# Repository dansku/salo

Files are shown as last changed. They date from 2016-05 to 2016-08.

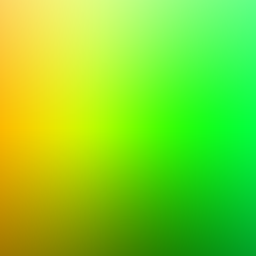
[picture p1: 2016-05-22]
vr/color_spectrum.framer/images/right.png

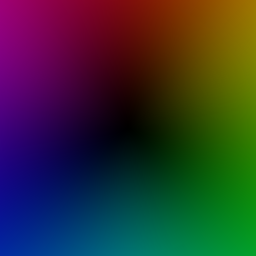
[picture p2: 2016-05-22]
vr/color_spectrum.framer/images/bottom.png

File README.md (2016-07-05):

# Salo Lamp

## Objectives 
* Develop a lamp connected to the internet where you can control it via a mobile application.
* Fully open source hardware/software
* Focus on low cost
* More to come...

## Dev Videos

<a href="http://www.youtube.com/watch?feature=player_embedded&v=c6tWdz0hgVQ
" target="_blank">salo lamp</a>

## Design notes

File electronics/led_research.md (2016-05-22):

# Led Research

http://aliexpress.com/store/product/10pcs-High-Power-LED-Chip-1W-COB-LED-Beads-Natural-Cool-Warm-White-Red-Blue-Green/1913069_32636756111.html

| Color | Temperature | [V] | [I] | [LM] |
|---|---|---|---|---|
| Red | 620-625nm | 2.0 - 2.2 V | 350mA | 50-60LM |
| Green | 520-525nm | 3.2 - 3.4 V | 350mA | 80-90LM |
| Blue | 460-470nm | 3.2 - 3.4 V | 350mA | 35-45LM |
| Warm White | 3000-3500 K | 3.2 - 3.4 V | 350mA | 100-110LM |

##Idea:

| Color | Number  | Total Current | Total Lumens |
|---|---|---|---|
| Warm White  | 4 | 1.4 A | 400 LM |
| Red | 6 | 2.1 A | 360 LM |
| Green | 4 | 1.4 A | 360 LM |
| Blue | 8 | 2.8 A | 360 LM |
| TOTAL (max) | 22 Leds | 7.7 A | 1480 LM |

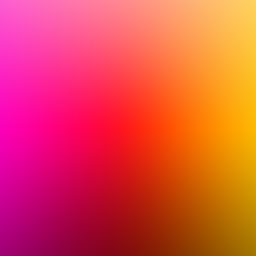
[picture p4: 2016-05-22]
vr/color_spectrum.framer/images/front.png

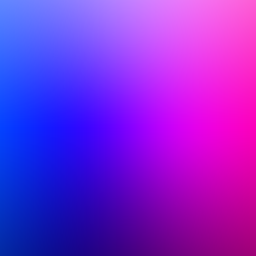
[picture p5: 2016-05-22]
vr/color_spectrum.framer/images/left.png

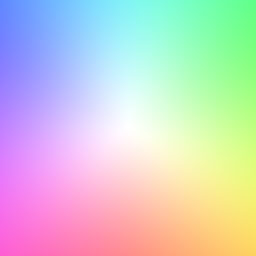
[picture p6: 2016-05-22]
vr/color_spectrum.framer/images/top.png

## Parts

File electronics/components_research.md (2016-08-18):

# Component Research

## Power Supply
https://www.reichelt.de/Wandler-Module-AC-DC/IRM-20-12/3/index.html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

## OSRAM LEDs
| Color | OSRAM Part Name | Temperature / Color | [V] | [I] | [LM] | Datasheet |
|---|---|---|---|---|---|---|
| Red | Q65111A2056 | 623 nm | 2.00 - 2.15 - 2.6  | 350mA | 58lm - 77lm/W  | http://bit.ly/2b00Kii |
| Green | Q65111A2266 | 528 nm | 2.75 - 3.20 - 3.5  | 350mA | 98 lm - 88lm/W | http://bit.ly/2b00ijR |
| Blue | Q65111A0403 | 470 nm | 2.75 - 3.20 - 3.5  | 350mA | 28 lm - 25lm/W | http://bit.ly/2aZZewz |
| Warm White | Q65111A3329 | 2700K | 2.80 - 2.95 - 3.25 | 350mA | 90 lm - 87lm/W | http://bit.ly/2b008ZZ |
| Cold White | Q65111A4248 | 4000K | 2.80 - 2.95 - 3.25 | 350mA | 90 lm - 87lm/W | http://bit.ly/2b008ZZ |

## LED Driver
AL5801W6-7 ( http://www.mouser.com/ds/2/115/AL5801-218664.pdf ) 350mA
VCC = 12V
Vrset = 0.56V
Iled = 350mA
Rbias = 82.5kOhm -> http://www.mouser.de/ProductDetail/Vishay-Dale/CRCW040282K5FKED/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
Rest = 1.6Ohm -> http://www.mouser.de/ProductDetail/Panasonic/ERJ-8GEYJ1R6V/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

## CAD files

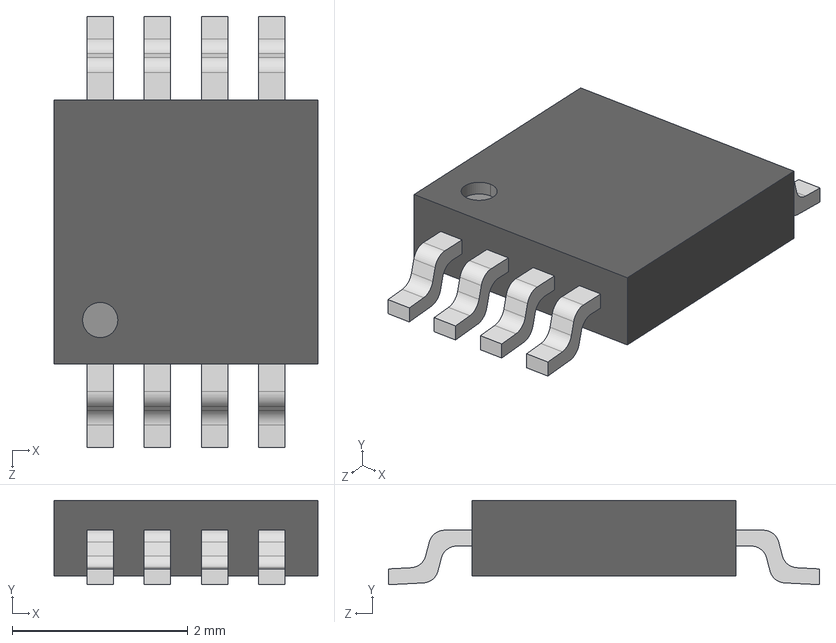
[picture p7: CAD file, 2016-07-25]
pcb/altium/components/User Library-MSOP-8-4.step
3.00 x 0.96 x 4.90 mm

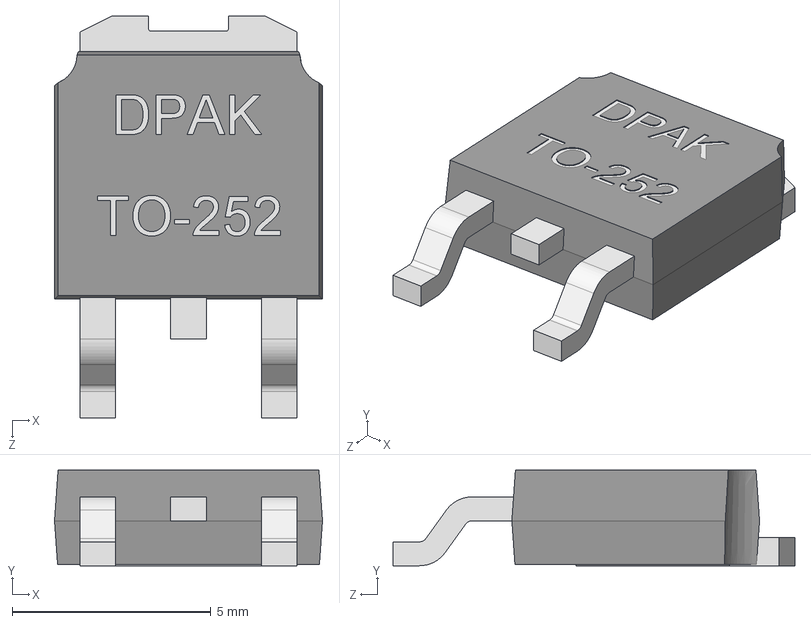
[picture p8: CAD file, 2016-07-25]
pcb/altium/components/DPAK_TO-252AA.step
6.73 x 2.40 x 10.1 mm

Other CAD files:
pcb/altium/components/DPAK_TO-252AA.stl

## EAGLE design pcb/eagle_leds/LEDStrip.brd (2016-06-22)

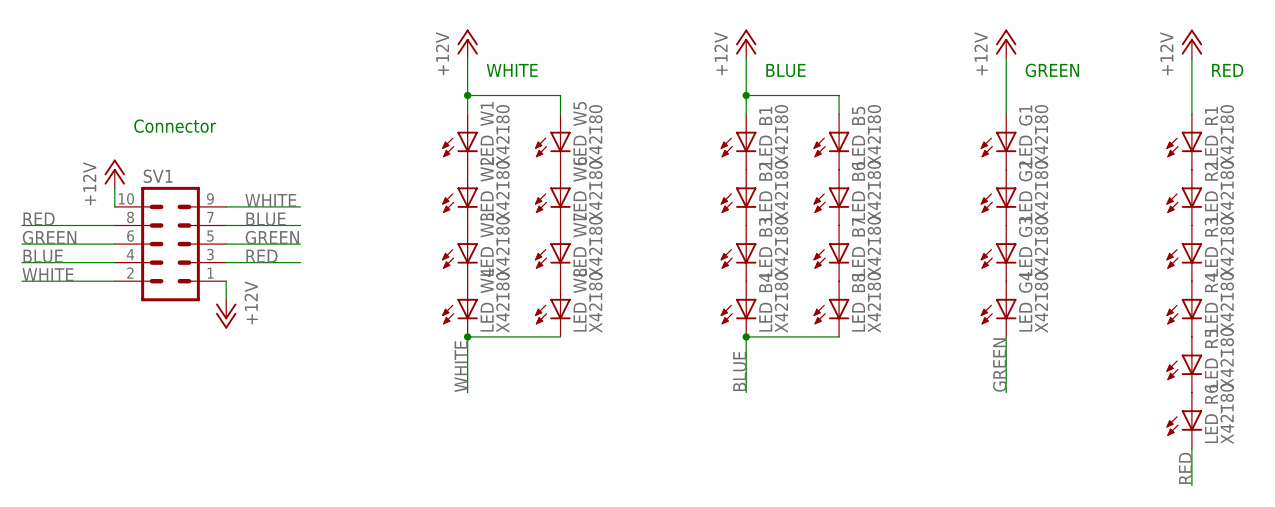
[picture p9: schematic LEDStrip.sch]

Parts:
LED_B1, LED_B2, LED_B3, LED_B4, LED_B5, LED_B6, LED_B7, LED_B8: X42180; Z-POWER-LED-DOME-TYPE
LED_G1, LED_G2, LED_G3, LED_G4: X42180; Z-POWER-LED-DOME-TYPE
LED_R1, LED_R2, LED_R3, LED_R4, LED_R5, LED_R6: X42180; Z-POWER-LED-DOME-TYPE
LED_W1, LED_W2, LED_W3, LED_W4, LED_W5, LED_W6, LED_W7, LED_W8: X42180; Z-POWER-LED-DOME-TYPE
SV1: MA05-2

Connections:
+12V: LED_B1.A, LED_B5.A, LED_G1.A, LED_R1.A, LED_W1.A, LED_W5.A, SV1.1, SV1.10
BLUE: LED_B4.C, LED_B8.C, SV1.4, SV1.7
GREEN: LED_G4.C, SV1.5, SV1.6
unnamed: LED_W1.C, LED_W2.A
unnamed: LED_W2.C, LED_W3.A
unnamed: LED_W3.C, LED_W4.A
unnamed: LED_W5.C, LED_W6.A
unnamed: LED_W6.C, LED_W7.A
unnamed: LED_W7.C, LED_W8.A
unnamed: LED_R4.C, LED_R5.A
unnamed: LED_B1.C, LED_B2.A
unnamed: LED_B2.C, LED_B3.A
unnamed: LED_B3.C, LED_B4.A
unnamed: LED_B5.C, LED_B6.A
unnamed: LED_B6.C, LED_B7.A
unnamed: LED_B7.C, LED_B8.A
unnamed: LED_G1.C, LED_G2.A
unnamed: LED_G2.C, LED_G3.A
unnamed: LED_G3.C, LED_G4.A
unnamed: LED_R1.C, LED_R2.A
unnamed: LED_R2.C, LED_R3.A
unnamed: LED_R3.C, LED_R4.A
unnamed: LED_R5.C, LED_R6.A
RED: LED_R6.C, SV1.3, SV1.8
WHITE: LED_W4.C, LED_W8.C, SV1.2, SV1.9

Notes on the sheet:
WHITE
BLUE
GREEN
RED
Connector

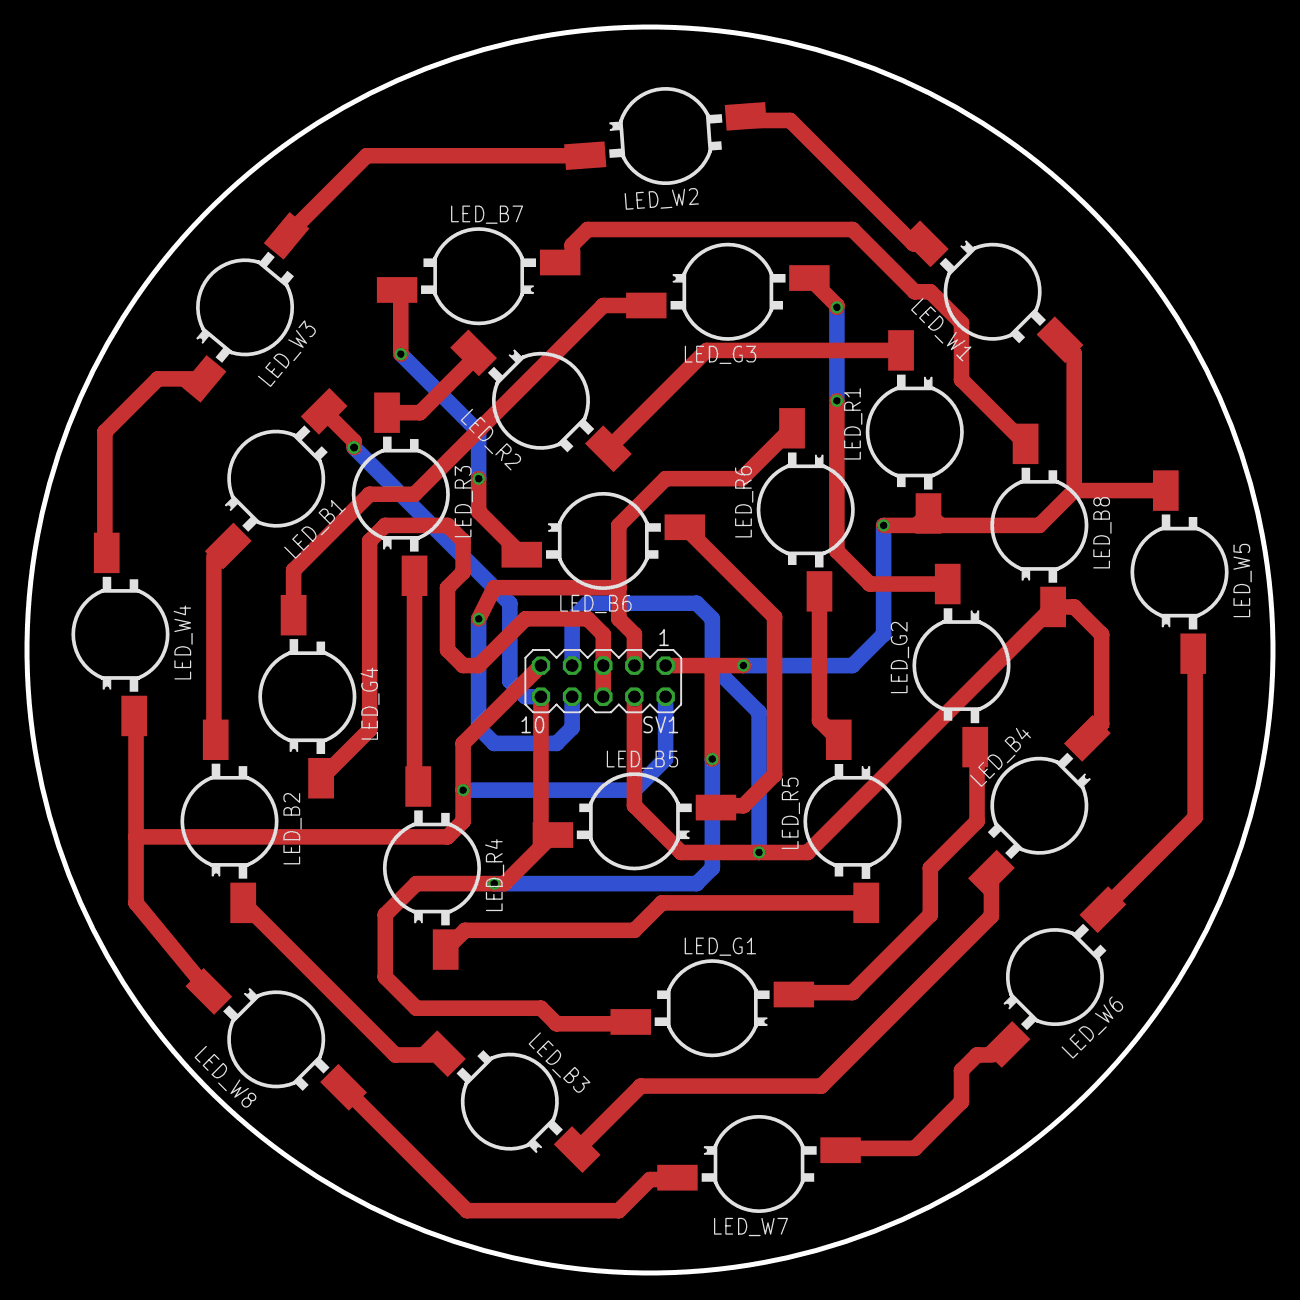
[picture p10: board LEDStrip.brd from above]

Board: 2 copper layers, 101.6 x 101.6 mm, 27 parts (0 on the bottom side), 25 nets.

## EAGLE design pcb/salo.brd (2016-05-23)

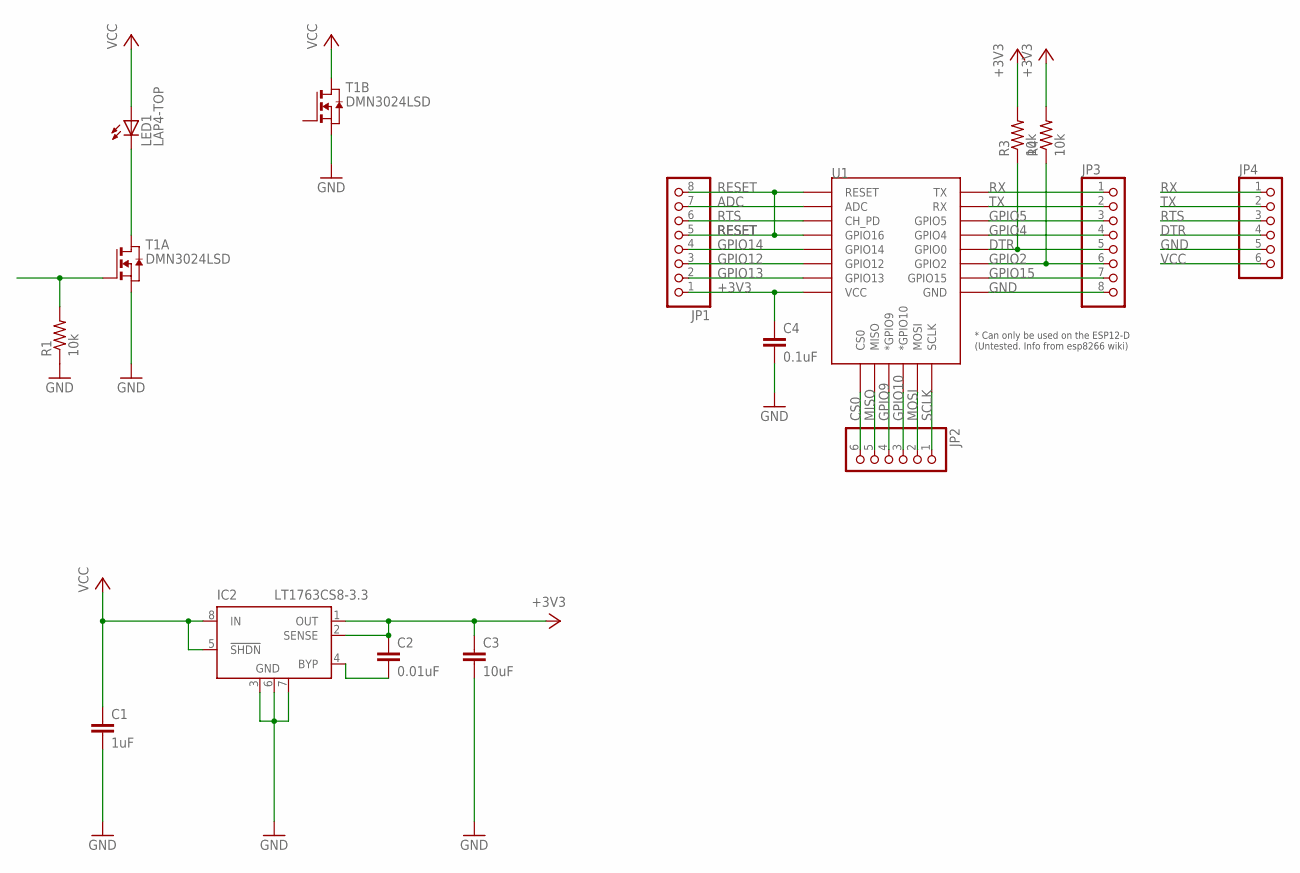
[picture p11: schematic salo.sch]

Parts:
C1: 1uF; C0805
C2: 0.01uF; C0805
C3: 10uF; C0805
C4: 0.1uF; C0805
IC2: LT1763CS8-3.3; SOIC8
JP1, JP3: PINHD-1X8; 1X08
JP2, JP4: PINHD-1X6; 1X06
LED1: LAP4-TOP; P47F-TOP
R1, R3, R4: 10k; R0805
T1: DMN3024LSD; SO8
U1: ESP12ESMD; ESP12E-SMD

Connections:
+3V3: C2.1, C3.1, C4.1, IC2.1 (OUT), IC2.2 (SENSE), JP1.1, R3.2, R4.2, U1.VCC
ADC: JP1.7, U1.ADC
BYPASS: C2.2, IC2.4 (BYP)
CS0: JP2.6, U1.CS0
DTR: JP3.5, JP4.4, R3.1, U1.GPIO0
GND: C1.2, C3.2, C4.2, IC2.3 (GND), IC2.6 (GND), IC2.7 (GND), JP3.8, JP4.5, R1.1, T1.1 (S), T1.3 (S), U1.GND
GPIO2: JP3.6, R4.1, U1.GPIO2
GPIO4: JP3.4, U1.GPIO4
GPIO5: JP3.3, U1.GPIO5
GPIO9: JP2.4, U1.GPIO9 (*GPIO9)
GPIO10: JP2.3, U1.GPIO10 (*GPIO10)
GPIO12: JP1.3, U1.GPIO12
GPIO13: JP1.2, U1.GPIO13
GPIO14: JP1.4, U1.GPIO14
GPIO15: JP3.7, U1.GPIO15
MISO: JP2.5, U1.MISO
MOSI: JP2.2, U1.MOSI
unnamed: R1.2, T1.2 (G)
unnamed: LED1.C, T1.7 (D), T1.8 (D)
RESET: JP1.5, JP1.8, U1.GPIO16, U1.RESET
RTS: JP1.6, JP4.3, U1.CH_PD
RX: JP3.1, JP4.1, U1.TXD0 (TX)
SCLK: JP2.1, U1.SCLK
TX: JP3.2, JP4.2, U1.RXD0 (RX)
VCC: C1.1, IC2.5 (!SHDN), IC2.8 (IN), JP4.6, LED1.A, T1.5 (D), T1.6 (D)

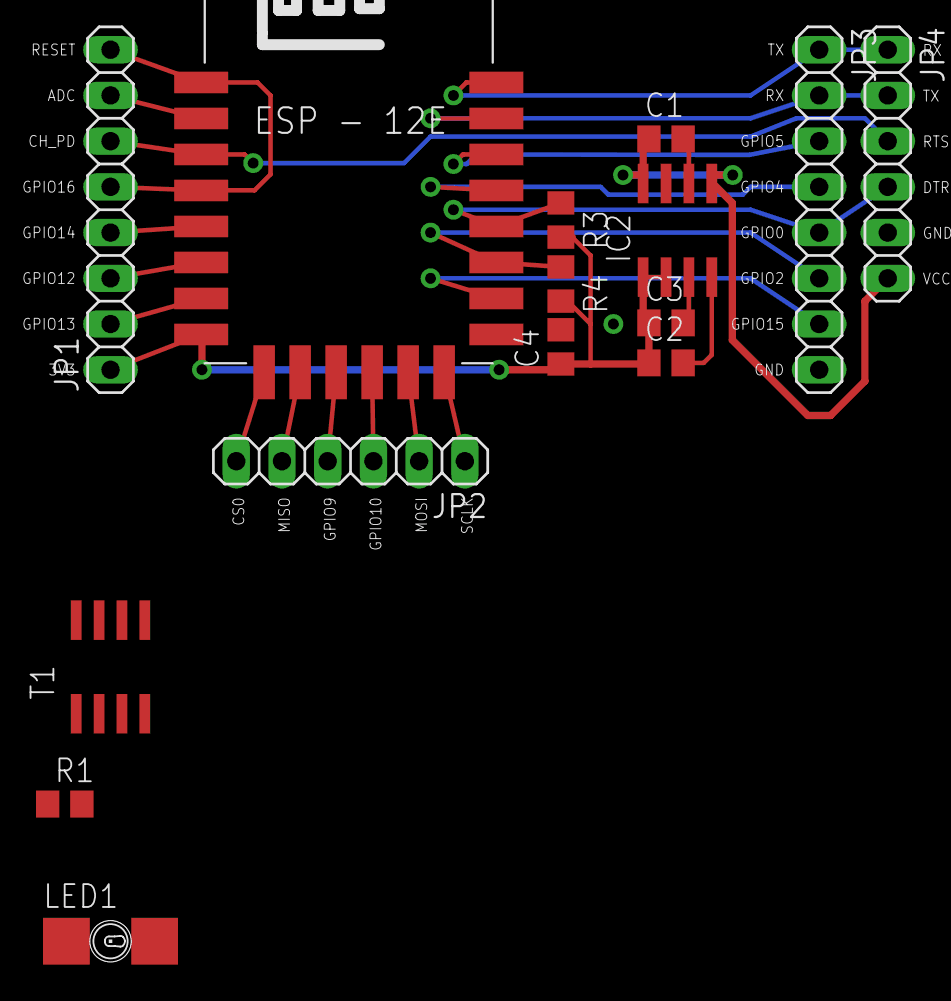
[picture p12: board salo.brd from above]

Board: 2 copper layers, 15 parts (0 on the bottom side), 25 nets.

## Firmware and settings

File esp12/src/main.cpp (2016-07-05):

// /*
//   Salo Lamp Project
//   2016
// */
//
#include <FS.h>
#include <ESP8266WiFi.h>
#include <DNSServer.h>
#include <ESP8266WebServer.h>
#include <WiFiManager.h>
#include <ThingerWebConfig.h>

// Debug
#define _DEBUG_

// Auto Config
ThingerWebConfig thing;

// Pins
/*
  13 = white
  12 = green
  14 = blue
  15 = red

green ok
blue  ok
red   no
white no

*/
uint8_t leds[4] = {13,15,12,14};                                                  // RED(D7) - GREEN(D6) - BLUE(D5) - WHITE(D0)
uint8_t reset   = 0;                                                              // Should we reset Wifi and Module settings

// Variables
uint8_t fadeSpeed = 15;                                                           //fading delay
uint16_t oldC[4], color[5];

// Set New Color
void setColor(uint8_t* leds, uint16_t* color)
{
  for(int i = 0; i <= 3; i++)
  {
    printf("Changing LED %d to %d \n", leds[i], color[i]);
    analogWrite(leds[i], color[i]);
  }
}

void fadeToColor(uint8_t* leds, uint16_t* startColor, uint16_t* endColor, int fadeSpeed)
{
  int changeRed   = endColor[0] - startColor[0];                                  //the difference in the two colors for the red channel
  int changeGreen = endColor[1] - startColor[1];                                  //the difference in the two colors for the green channel
  int changeBlue  = endColor[2] - startColor[2];                                  //the difference in the two colors for the blue channel
  int changeWhite = endColor[3] - startColor[3];
  int steps = max(abs(changeRed),max(abs(changeGreen), abs(changeBlue)));         //make the number of change steps the maximum channel change

  for(int i = 0 ; i < steps; i++){                                                //iterate for the channel with the maximum change
    uint16_t newRed      = startColor[0] + (i * changeRed / steps);                //the newRed intensity dependant on the start intensity and the change determined above
    uint16_t newGreen    = startColor[1] + (i * changeGreen / steps);              //the newGreen intensity
    uint16_t newBlue     = startColor[2] + (i * changeBlue / steps);
    uint16_t newWhite    = startColor[3] + (i * changeWhite / steps);              //the newBlue intensity
    uint16_t newColor[]  = {newRed, newGreen, newBlue, newWhite};                  //Define an RGB color array for the new color
    setColor(leds, newColor);
    delay(fadeSpeed);                                                             //Set the LED to the calculated value
  }
}

void setup()
{

  // Serial YO!
  Serial.begin(115200);
  printf("Lamp starting \n");
  pinMode(13, INPUT);

  //Reset option
  if(13==HIGH)
  {
    printf("RESET ON \n");
    WiFiManager wifiManager;
    wifiManager.resetSettings();
  }
  else
  {
    printf("RESET OFF \n");
  }

  // Everytime a websocket msg is received
  thing["colors"] << [](pson& in){

    // Update old color array
    for(int i=0;i<=3;i++)
    {
      oldC[i] = color[i];
    }

    color[0] = in["white"];
    color[1] = in["red"];
    color[2] = in["green"];
    color[3] = in["blue"];
    color[4] = in["fade"];
    color[5] = in["fadeSpeed"];

    color[4] == 1 ? fadeToColor(leds, oldC, color, fadeSpeed) : setColor(leds, color);  // Select if we want fade or not

  };
}

void loop()
{
  thing.handle();
}

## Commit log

2016-05-22 Add LED research/idea
2016-05-22 Add Eagle starting files.
    [salo.brd, salo.sch]
2016-05-23 Add 2x N-channel enhancement MOSFET, SO-8.
    [salo.brd, salo.sch]
2016-05-23 Add fadeToColor function. May be inverted for now.
    [main.cpp]
2016-05-24 Changed Serial.print to printf.
2016-06-01 Create test bed pcb.
    [led_test.PcbDoc, led_test.PrjPCB, led_test.SchDoc]
2016-06-22 Add test leds pcb
    [LEDStrip.brd, LEDStrip.sch]
2016-07-02 Update with led count
2016-07-05 Update pin numbers as red was bliking on boot.
2016-07-25 Update files.
    [DPAK_TO-252AA.step, DPAK_TO-252AA.stl, SALO_CONTROLLER_PCB.PcbDoc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]
2016-07-25 Add gitignore
    [SALO_CONTROLLER_PCB.SchDoc]
2016-08-17 Update red voltage
2016-08-18 Add led driver
2016-08-18 Add Led Driver resistors

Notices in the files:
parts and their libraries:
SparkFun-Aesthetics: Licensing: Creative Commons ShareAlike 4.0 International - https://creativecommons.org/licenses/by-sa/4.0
